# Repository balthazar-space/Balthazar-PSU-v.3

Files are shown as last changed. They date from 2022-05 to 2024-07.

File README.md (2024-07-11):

# Balthazar

Open-hardware laptop computer modules description and concept.

These are electronic schematic modules as presented at https://balthazar.space/wiki/Balthazar with the main aim for team access. See the [main repository](https://github.com/balthazar-space/balthazar) for other designs.

# Balthazar PSU v.3 

Module BalthazarPSU3 is a combined 1S battery charger, buck-boost converter to 5V, boost converter to 12V and stereo power amplifier. 

KiCad 6.99 files.

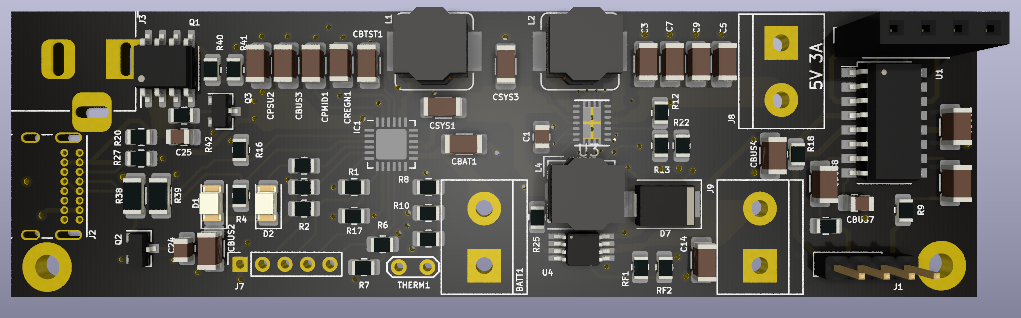
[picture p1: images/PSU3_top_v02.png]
Top


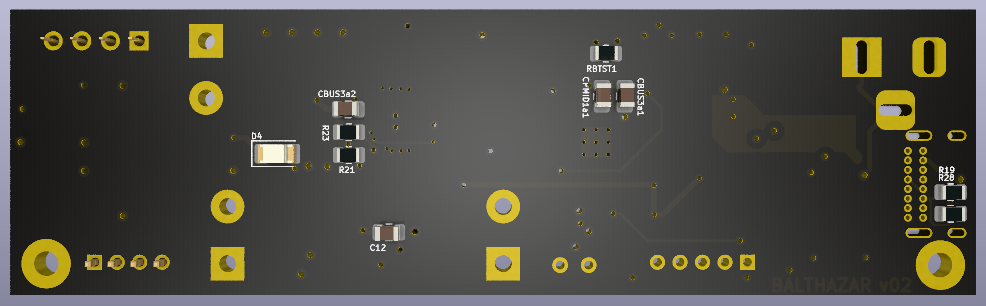
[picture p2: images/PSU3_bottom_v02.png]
Bottom


## License

All resources except the keyboard firmware - which is licensed with with GPLv3 or later - licensed under the CERN Open Hardware Licence CERN-OHL W V.2.0

Version 2.0 of the CERN-OHL introduces three variants of the licence – strongly (S) reciprocal, weakly (W) reciprocal and permissive (P) – which aim to address specific constraints caused by different collaboration models currently used in open-hardware projects. 

The first two variants mean that if any product is made using an open hardware design, the design of that product, including any improvements or modifications, should be made available under the same licence as that of the original product. Permissive licences do not impose this condition.

See the [LICENSE.md](./LICENSE.md) file for more information.

## Funding

This project is funded through the [NGI Zero Entrust Fund](https://nlnet.nl/entrust), a fund
established by [NLnet](https://nlnet.nl) with financial support from the European Commission's
[Next Generation Internet](https://ngi.eu) program. Learn more on the [NLnet project page](https://nlnet.nl/project/Balthazar-Casing/).

[NLNet foundation logo](https://nlnet.nl)
[NGI0 Entrust Logo](https://nlnet.nl/entrust)

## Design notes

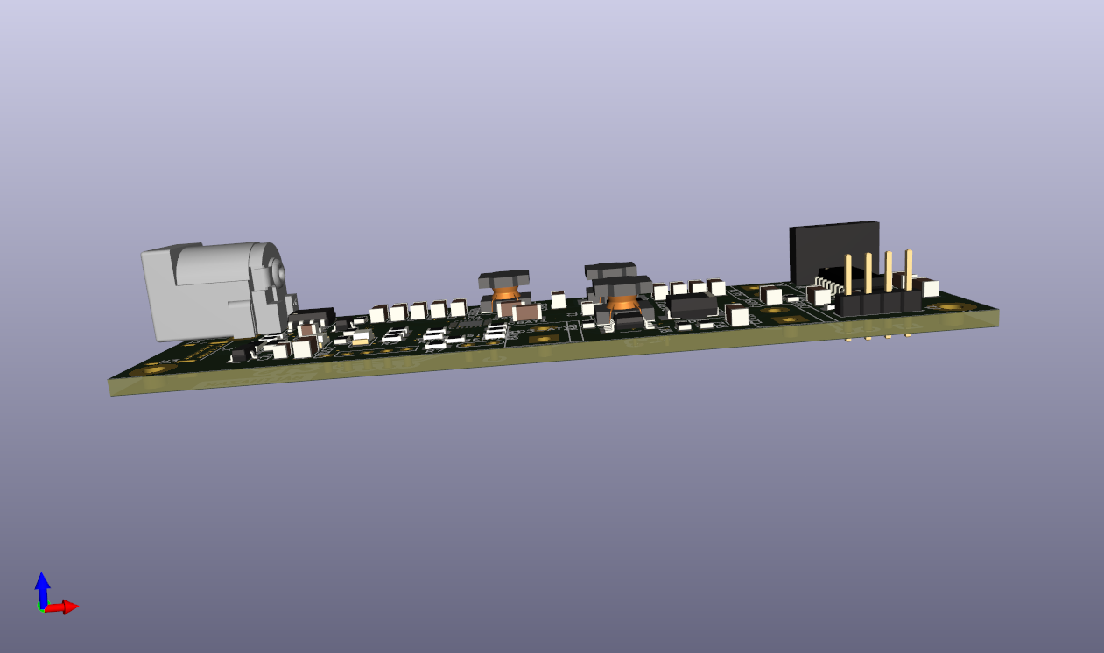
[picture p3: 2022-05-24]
images/BalthazarPSU3-3.png

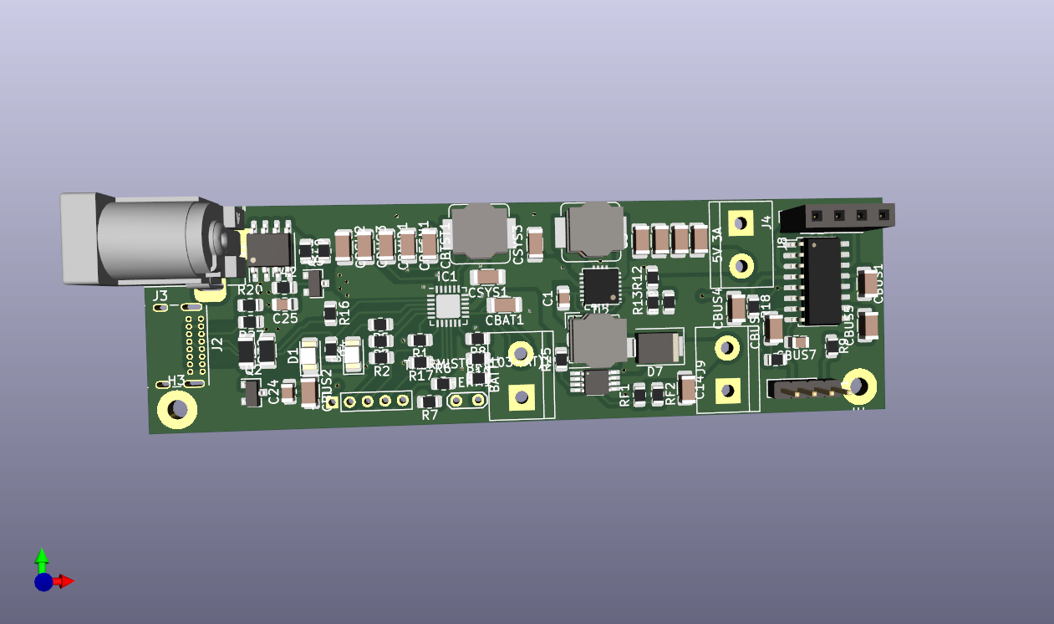
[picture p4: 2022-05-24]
images/BalthazarPSU3-1.png

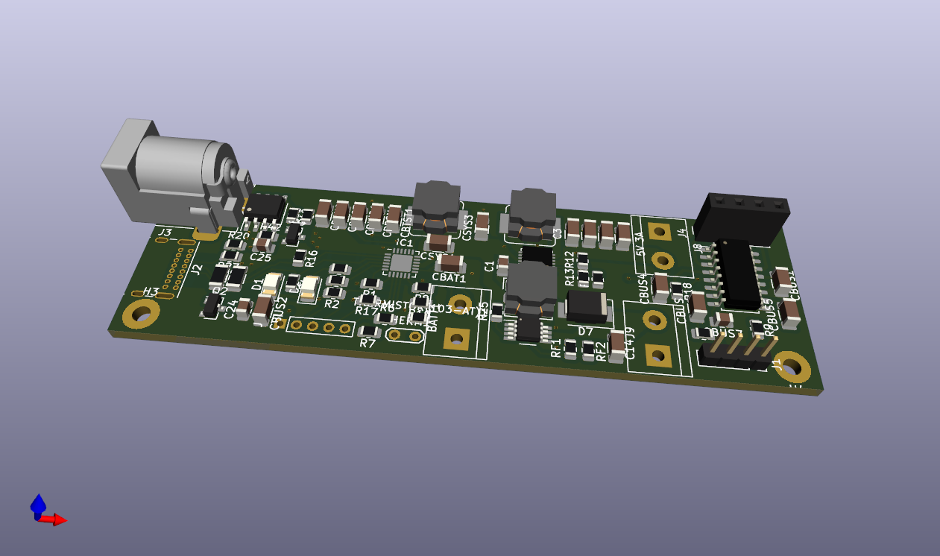
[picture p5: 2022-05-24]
images/BalthazarPSU3-2.png

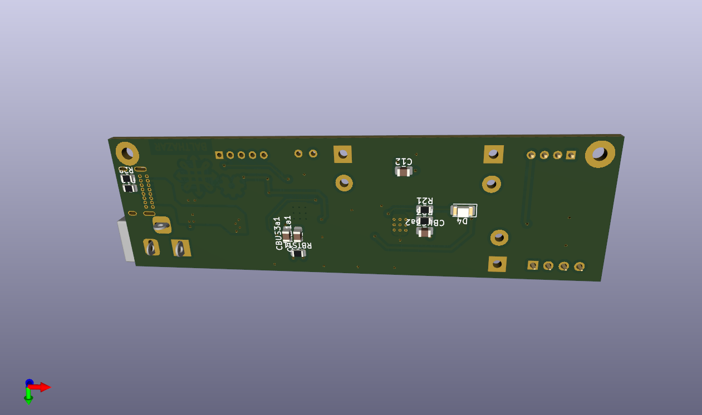
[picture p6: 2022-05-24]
images/BalthazarPSU3-4.png

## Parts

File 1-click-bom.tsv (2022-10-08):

References | Qty | Description | Manufacturer | MPN | Manufacturer | MPN | Manufacturer | MPN | Manufacturer | MPN | Digikey | Mouser | RS | Newark | Farnell | LCSC | JLC Assembly
C1, C24, CBUS3a1, CBUS3a2, CBUS7, CPMID1a1 | 6 | 0.1uF C_0805_2012Metric | KEMET | C0402C104K4RACTU | Yageo | CC0805KRX7R9BB104 | Murata | GRM21BR71H104KA01L |  |  | 311-1140-6-ND | 80C0402C104K4R | 8015145P |  | 1288252
C3, C5, C7, C9, C14 | 5 | 22uF C_1206_3216Metric | AVX | 12066C226KAT2A | Taiyo Yuden | EMK316ABJ226ML-T |  |  |  |  | 587-3328-6-ND | 963EMK316ABJ226MLT | 1356734 |  | 1657942
C12 | 1 | 4.7pF C_0805_2012Metric | KEMET | C0805C479C5GACTU | KEMET | C0805C479D5GACTU |  |  |  |  | 399-C0805C479D5GAC7800DKR-ND | 80C0805C479D5G | 1464340P |  | 1800809
C25 | 1 | 1nF C_0805_2012Metric | KEMET | C0805C102J1GACTU | KEMET | C0805C102K5RACTU |  |  |  |  | 399-C0805C102K5RAC7800DKR-ND | 80C0805C102K5R | 8029958P |  | 1414660
R1, R2, R3, R6, R16, R17, R18, R42 | 8 | 10K R_0805_2012Metric | Panasonic | ERJ-3EKF1002V | Panasonic | ERJ-6ENF1002V | TE Connectivity | CPF0805B10KE | Panasonic | ERJ-6GEYJ103V | P10.0KHCT-ND | 667ERJ6ENF1002V | 6662594 |  | 2303192
R4, R5, R8, R9, R11, R21 | 6 | 2K2 R_0805_2012Metric | Panasonic | ERJ-2RKF2201X | Panasonic | ERJ-3GEYJ222V | TE Connectivity | CRG0805F2K2 | Panasonic | ERJP06F2201V | P2.2KGCT-ND | 667ERJ2RKF2201X | 7217775P |  | 1750759
R12, R23 | 2 | 1M R_0805_2012Metric | Panasonic | ERJ-3GEYJ105V | Panasonic | ERJ-6GEYJ105V |  |  |  |  | P1.0MGCT-ND | 667ERJ3GEYJ105V | 7326536 |  | 2057738
R19, R27 | 2 | 5K1 R_0805_2012Metric | Panasonic | ERJ-6ENF5101V | Yageo | RC0805FR-075K1L |  |  |  |  | 311-5.10KCRDKR-ND | 667ERJ6ENF5101V | 1995733P |  | 3496074
R20, R28 | 2 | 56K 0805_2012Metric | Yageo | RMCF0805JT56K0 | Yageo | AC0805FR-0756KL | Yageo | RC0805FR-0756KL |  |  | 311-56.0KCRCT-ND | 603RC0805FR0756KL | 1995730 |  | 9237844
R7 | 1 | 270R 0805_2012Metric | TE Connectivity | 3520270RJT | TE Connectivity | CRG0805F270R | Panasonic | ERJ-6GEYJ271V |  |  | A126355CT-ND | 667ERJ6GEYJ271V | 2240339 |  | 3399601
R10 | 1 | 6K8 0805_2012Metric | Yageo | RC0805FR-076K8L | Yageo | AC0805FR-076K8L |  |  |  |  | 311-6.80KCRCT-ND | 603AC0805FR076K8L | 1995745 |  | 9237739RL
R13 | 1 | 180K R_0805_2012Metric | Yageo | RC0805JR-07180KL | Bourns | CR0805-JW-184ELF |  |  |  |  | 311-180KARCT-ND | 603RC0805JR07180KL |  |  | 9234284
R22 | 1 | 270K R_0805_2012Metric | Yageo | RC0805JR-07270KL |  | RC0805JR-07270KL |  |  |  |  | 311-270KARDKR-ND | 603RC0805JR07270KL |  |  | 9234306
R25 | 1 | 150K R_0805_2012Metric | Yageo | RC0805JR-07150KL |  | RC0805JR-07150KL |  |  |  |  | 311-150KARDKR-ND | 603RC0805JR07150KL |  |  | 9234276
R38 | 1 | 120K R_1206_3216Metric | Yageo | AC1206JR-07150KL |  | AC1206JR-07150KL |  |  |  |  | YAG3920CT-ND | 603AC1206JR07150KL
R39 | 1 | 49K9 R_1206_3216Metric | Yageo | RC1206FR-0749K9L |  | RC1206FR-0749K9L |  |  |  |  | 311-49.9KFRCT-ND | 603RC1206FR0749K9L |  |  | 3951060RL
R40 | 1 | 270K R_0805_2012Metric | Yageo | RC0805JR-07270KL |  | RC0805JR-07270KL |  |  |  |  | 311-270KARDKR-ND | 603RC0805JR07270KL |  |  | 9234306
R41 | 1 | 100K R_0805_2012Metric | Yageo | RC0805FR-13100KL |  | RC0805FR-13100KL |  |  |  |  | 13-RC0805FR-13100KLDKR-ND | 603RC0805FR13100KL |  |  | 3951189RL
L1 | 1 | 2.2uH SRP7028A | Bourns | SRP7028A-2R2M |  |  |  |  |  |  | SRP7028A-2R2MCT-ND | 652SRP7028A2R2M |  |  | 2434097
L2 | 1 | 1.5uH SRP7028A | Bourns | SRP7028A-1R5M |  |  |  |  |  |  | SRP7028A-1R5MCT-ND | 652SRP7028A1R5M | 2231849P |  | 2434095
L4 | 1 | 4.7uH SRP5030T | Bourns | SRP5030T-4R7M |  |  |  |  |  |  | SRP5030T-4R7MDKR-ND | 652SRP5030T4R7M | 7763985P |  | 2309887
D1, D2, D4 | 3 | Led LED_1206_3216Metric | Stanley Electric | RPG1102W-660-TR |  | RPG1102W-660-TR |  |  |  |  | 404-1232-1-ND | 327RPG1102W660TR
D7 | 1 | B320 | Bourns | CD214B-B320R | Diodes Inc. | B320B-13-F | Diodes Inc. | B330-13-F |  |  | B320B-FDICT-ND | 652CD214BB320R | 7513269 |  | 3944811RL
U1 | 1 | PAM8403 | Diodes Inc. | PAM8403DR-H | Diodes Inc. | PAM8403DR |  |  |  |  | PAM8403DR-HDICT-ND | 621PAM8403DRH | 7902975P |  | 3373823
U2 | 1 | TPS63020 | Texas Instruments | TPS63020DSJT |  |  |  |  |  |  | 296-27230-2-ND | 595TPS63020DSJT | 8123808 |  | 3007458
U4 | 1 | LM2623 | Texas Instruments | LM2623AMM/NOPB | Texas Instruments | LM2623MM/NOPB |  |  |  |  | LM2623AMM/NOPBCT-ND | 926LM2623AMM/NOPB | 5333901 |  | 3121524RL
CBTST1, CBUS2, CBUS3, CBUS5, CBUS8, CPSU2, CREGN1 | 7 | 1uF C_1206_3216Metric | KEMET | C1206C105K3RACTU |  |  |  |  |  |  | 399-C1206C105K3RAC7800DKR-ND | 80C1206C105K3R | 4348110P |  | 9227865
CBAT1, CBUS1, CBUS4, CPMID1, CSYS1, CSYS3 | 6 | 10uF C_1206_3216Metric | KEMET | T491A106M016AT |  |  |  |  |  |  | 399-3687-6-ND | 80T491A106M016 | 8015454P |  | 1650980
Q2, Q3 | 2 | BSS138 | Nexperia | BSS138P,215 | Nexperia | BSS138BK,215 | ROHM | BSS138BKT116 |  |  | 846-BSS138BKT116CT-ND | 771BSS138P215 | 7920891P |  | 2053833
BATT1 | 1 | 1s LiPo TerminalBlock_bornier-2_P5.08mm |  | OQ0254500000G |  |  |  |  |  |  |  | 649OQ02545000J0G
IC1 | 1 | BQ24193 | Texas Instruments | BQ24193RGER |  |  |  |  |  |  | 296-35046-2-ND | 595BQ24193RGER
Q1 | 1 | IRF7404 | Infineon | IRF7404TRPBF |  |  |  |  |  |  | IRF7404PBFCT-ND | 942IRF7404TRPBF | 1781525 |  | 2468018
RBTST1 | 1 | R R_0805_2012Metric
RF1 | 1 | 820K R_0805_2012Metric | TE Connectivity | CRGP0805F820K | Panasonic | ERA6AEB824V |  |  |  |  | A130512DKR-ND | 279CRGP0805F820K | 566418P |  | 2861130
RF2 | 1 | 100K R_0805_2012Metric | Panasonic | ERJ-6ENF1003V | TE Connectivity | CPF0805B100KE |  |  |  |  | P100KCDKR-ND | 667ERJ6ENF1003V | 6662673P |  | 2303757
THERM1 | 1 | thermistor TestPoint_2Pads_Pitch2.54mm_Drill0.8mm
THERMISTOR(103-AT)1 | 1 | 10K R_0805_2012Metric | Panasonic | ERJ-6ENF1002V | TE Connectivity | CPF0805B10KE |  |  |  |  | A106043CT-ND | 667ERJ6ENF1002V | 6662594 |  | 2303654
J1 | 1 | AudioIN PinSocket_1x04_P2.00mm_Vertical |  | SQT-102-03-F-S |  |  |  |  |  |  |  | 200SQT10203FS
J2 | 1 | USB_C_Receptacle_USB2.0 USB_C_Receptacle_GCT_USB4085 |  | USB4085-GF-A |  |  |  |  |  |  |  | 640USB4085GFA
J3 | 1 | 5-15V / 3-5A BarrelJack_Horizontal |  | PRT-00119 |  |  |  |  |  |  |  | 474PRT00119
J4 | 1 | AudioOUT PinSocket_1x04_P2.54mm_Vertical |  | 929850-01-04-RA |  |  |  |  |  |  |  | 5179298500104RA
J7 | 1 | uC host PinSocket_1x05_P2.00mm_Vertical |  | SQT-105-01-F-S |  |  |  |  |  |  |  | 200SQT10501FS
J8 | 1 | 5V 3A TerminalBlock_bornier-2_P5.08mm |  | OQ0254500000G |  |  |  |  |  |  |  | 649OQ02545000J0G
J9 | 1 | 12V 2A TerminalBlock_bornier-2_P5.08mm |  | OQ0254500000G |  |  |  |  |  |  |  | 649OQ02545000J0G

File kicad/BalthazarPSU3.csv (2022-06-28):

Id | Designator | Footprint | Quantity | Designation | Supplier and ref
1 | CBAT1,CBUS1,CBUS4,CPMID1,CSYS1,CSYS3 | C_1206_3216Metric | 6 | 10uF
2 | CBTST1,CBUS2,CBUS3,CBUS5,CBUS8,CPSU2,CREGN1 | C_1206_3216Metric | 7 | 1uF
3 | CBUS7,C1,C24,CBUS3a1,CBUS3a2,CPMID1a1 | C_0805_2012Metric | 6 | 0.1uF
4 | D1,D2,D4 | LED_1206_3216Metric | 3 | Led
5 | R4,R5,R8,R9,R11,R21 | R_0805_2012Metric | 6 | 2K2
6 | R7 | R_0805_2012Metric | 1 | 265
7 | R10 | R_0805_2012Metric | 1 | 6K8
8 | C3,C5,C7,C9,C14 | C_1206_3216Metric | 5 | 22uF
9 | R12,R23 | R_0805_2012Metric | 2 | 1M
10 | R13 | R_0805_2012Metric | 1 | 180K
11 | THERMISTOR(103-AT)1,R18,R42,R1,R2,R3,R6,R16,R17 | R_0805_2012Metric | 9 | 10K
12 | U1 | SOP-16_4.55x10.3mm_P1.27mm | 1 | PAM8403-SOP16
13 | IC1 | QFN-24-1EP_4x4mm_P0.5mm_EP2.7x2.7mm_ThermalVias | 1 | BQ24193
14 | THERM1 | TestPoint_2Pads_Pitch2.54mm_Drill0.8mm | 1 | thermistor
15 | R25 | R_0805_2012Metric | 1 | 150K
16 | U2 | WSON-14-1EP_4.0x4.0mm_P0.5mm_EP2.6x2.6mmThermalPads | 1 | TPS63020
17 | BATT1 | TerminalBlock_bornier-2_P5.08mm | 1 | 1s LiPo
18 | J8 | TerminalBlock_bornier-2_P5.08mm | 1 | 5V 2A
19 | J9 | TerminalBlock_bornier-2_P5.08mm | 1 | 12V 2A
20 | J2 | USB_C_Receptacle_GCT_USB4085 | 1 | USB_C_Receptacle_USB2.0
21 | L1 | L_Bourns_SRP7028A_7.3x6.6mm | 1 | 2.2uH 4A
22 | L2 | L_Bourns_SRP7028A_7.3x6.6mm | 1 | 1.5uH 4A
23 | J3 | TerminalBlock_bornier-2_P5.08mm | 1 | 5-15V/3A
24 | C25 | C_0805_2012Metric | 1 | 1nF
25 | Q2,Q3 | SOT-23 | 2 | BSS138
26 | R20,R28 | R_0805_2012Metric | 2 | 56K
27 | R27,R19 | R_0805_2012Metric | 2 | 5K1
28 | R40 | R_0805_2012Metric | 1 | 262K
29 | R41,RF2 | R_0805_2012Metric | 2 | 100K
30 | J4 | PinSocket_1x04_P2.54mm_Vertical | 1 | AudioOUT
31 | J7 | PinSocket_1x05_P2.00mm_Vertical | 1 | uC host
32 | J1 | PinSocket_1x04_P2.00mm_Vertical | 1 | AudioIN
33 | R38 | R_1206_3216Metric | 1 | 120K
34 | R39 | R_1206_3216Metric | 1 | 49K9
35 | H1,H3,H4 | MountingHole_2.2mm_M2_Pad | 3 | MountingHole_Pad
36 | Q1 | SOIC-8_3.9x4.9mm_P1.27mm | 1 | IRF7404
37 | RF1 | R_0805_2012Metric | 1 | 820K
38 | L4 | L_Bourns_SRP5030T | 1 | 4.7uH 2A
39 | D7 | D_SMB | 1 | B320
40 | R22 | R_0805_2012Metric | 1 | 270K
41 | U4 | VSSOP-8_3.0x3.0mm_P0.65mm | 1 | LM2623
42 | RBTST1 | R_0805_2012Metric | 1 | R
43 | G*** | BALTHAZARlogo150 | 1 | LOGO
44 | C12 | C_0805_2012Metric | 1 | 4.7pF

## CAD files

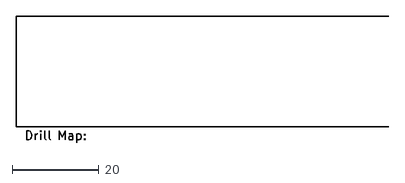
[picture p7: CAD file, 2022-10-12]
kicad/gerbers/BalthazarPSU3-NPTH-drl_map.dxf
85.9 x 29.1

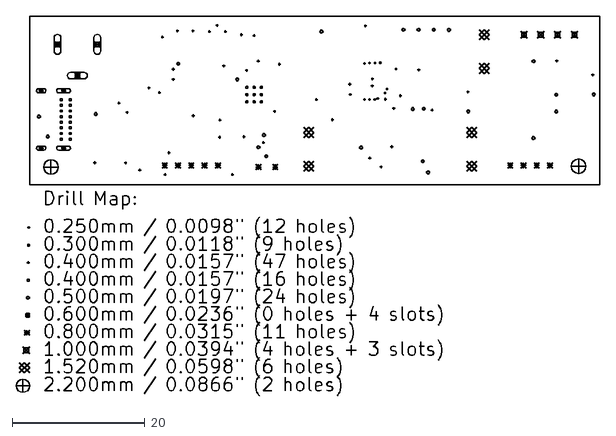
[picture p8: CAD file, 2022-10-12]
kicad/gerbers/BalthazarPSU3-PTH-drl_map.dxf
87.9 x 57.2

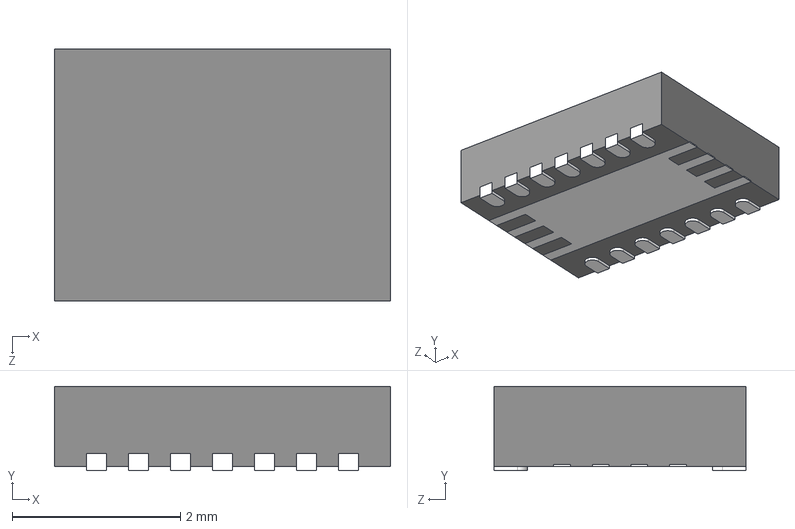
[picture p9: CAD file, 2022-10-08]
kicad/footprint/TPS63020/TPS63020.step
4.00 x 1.00 x 3.00 mm

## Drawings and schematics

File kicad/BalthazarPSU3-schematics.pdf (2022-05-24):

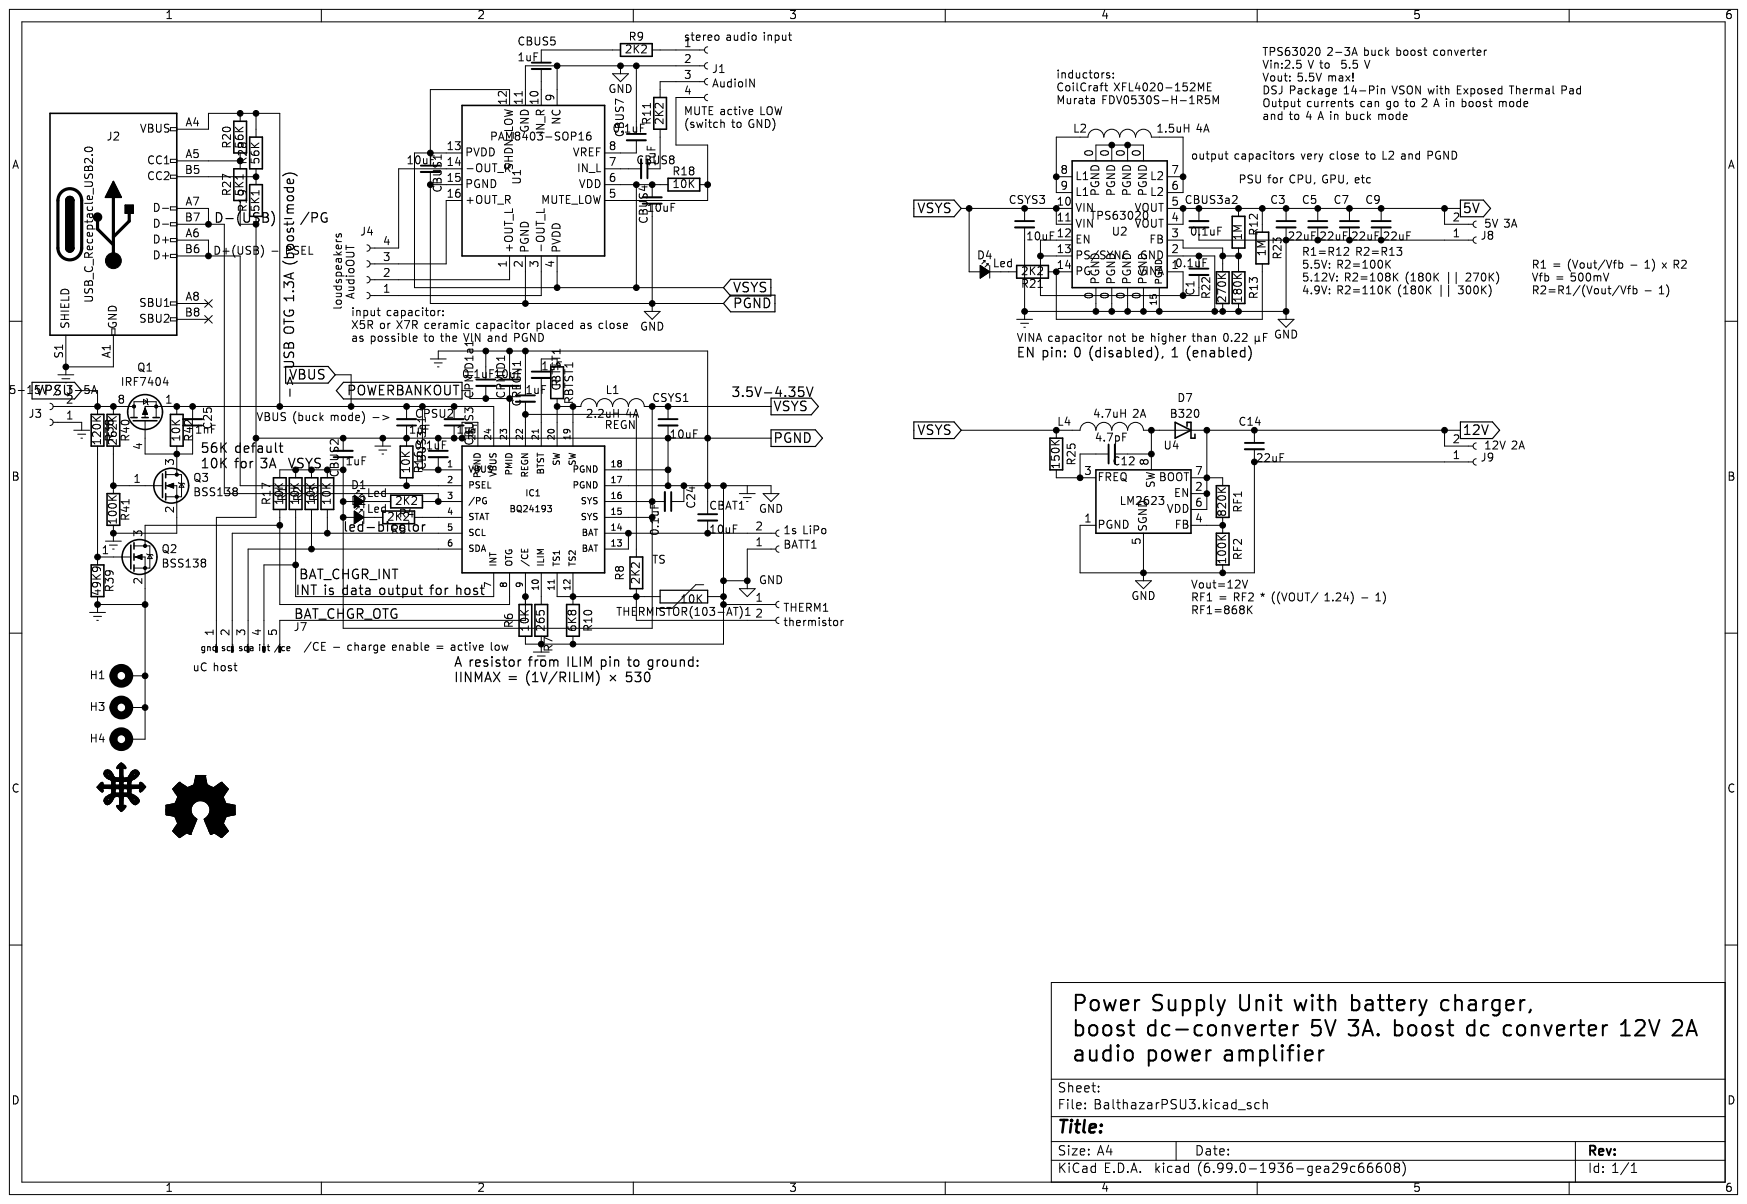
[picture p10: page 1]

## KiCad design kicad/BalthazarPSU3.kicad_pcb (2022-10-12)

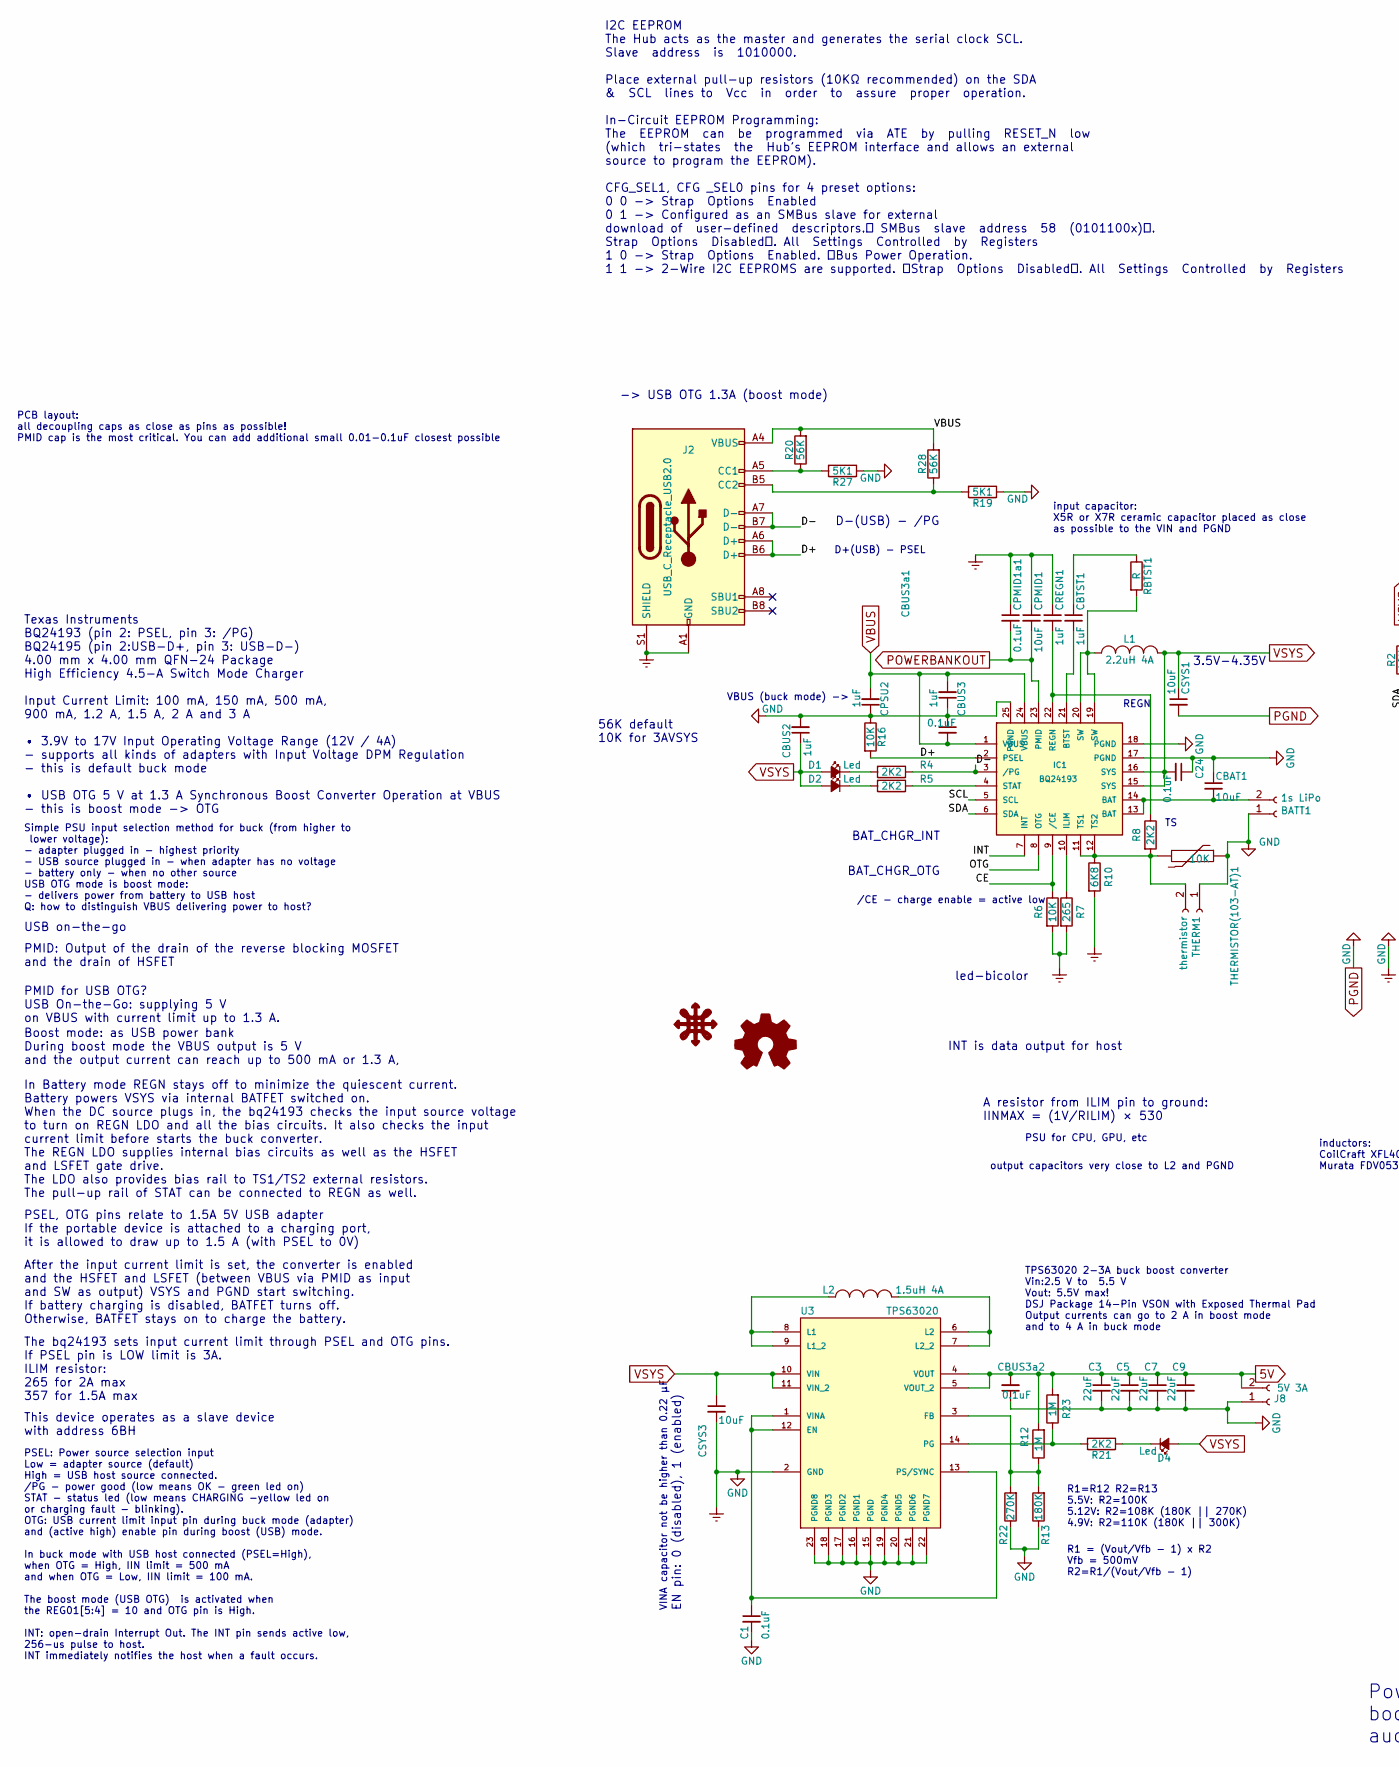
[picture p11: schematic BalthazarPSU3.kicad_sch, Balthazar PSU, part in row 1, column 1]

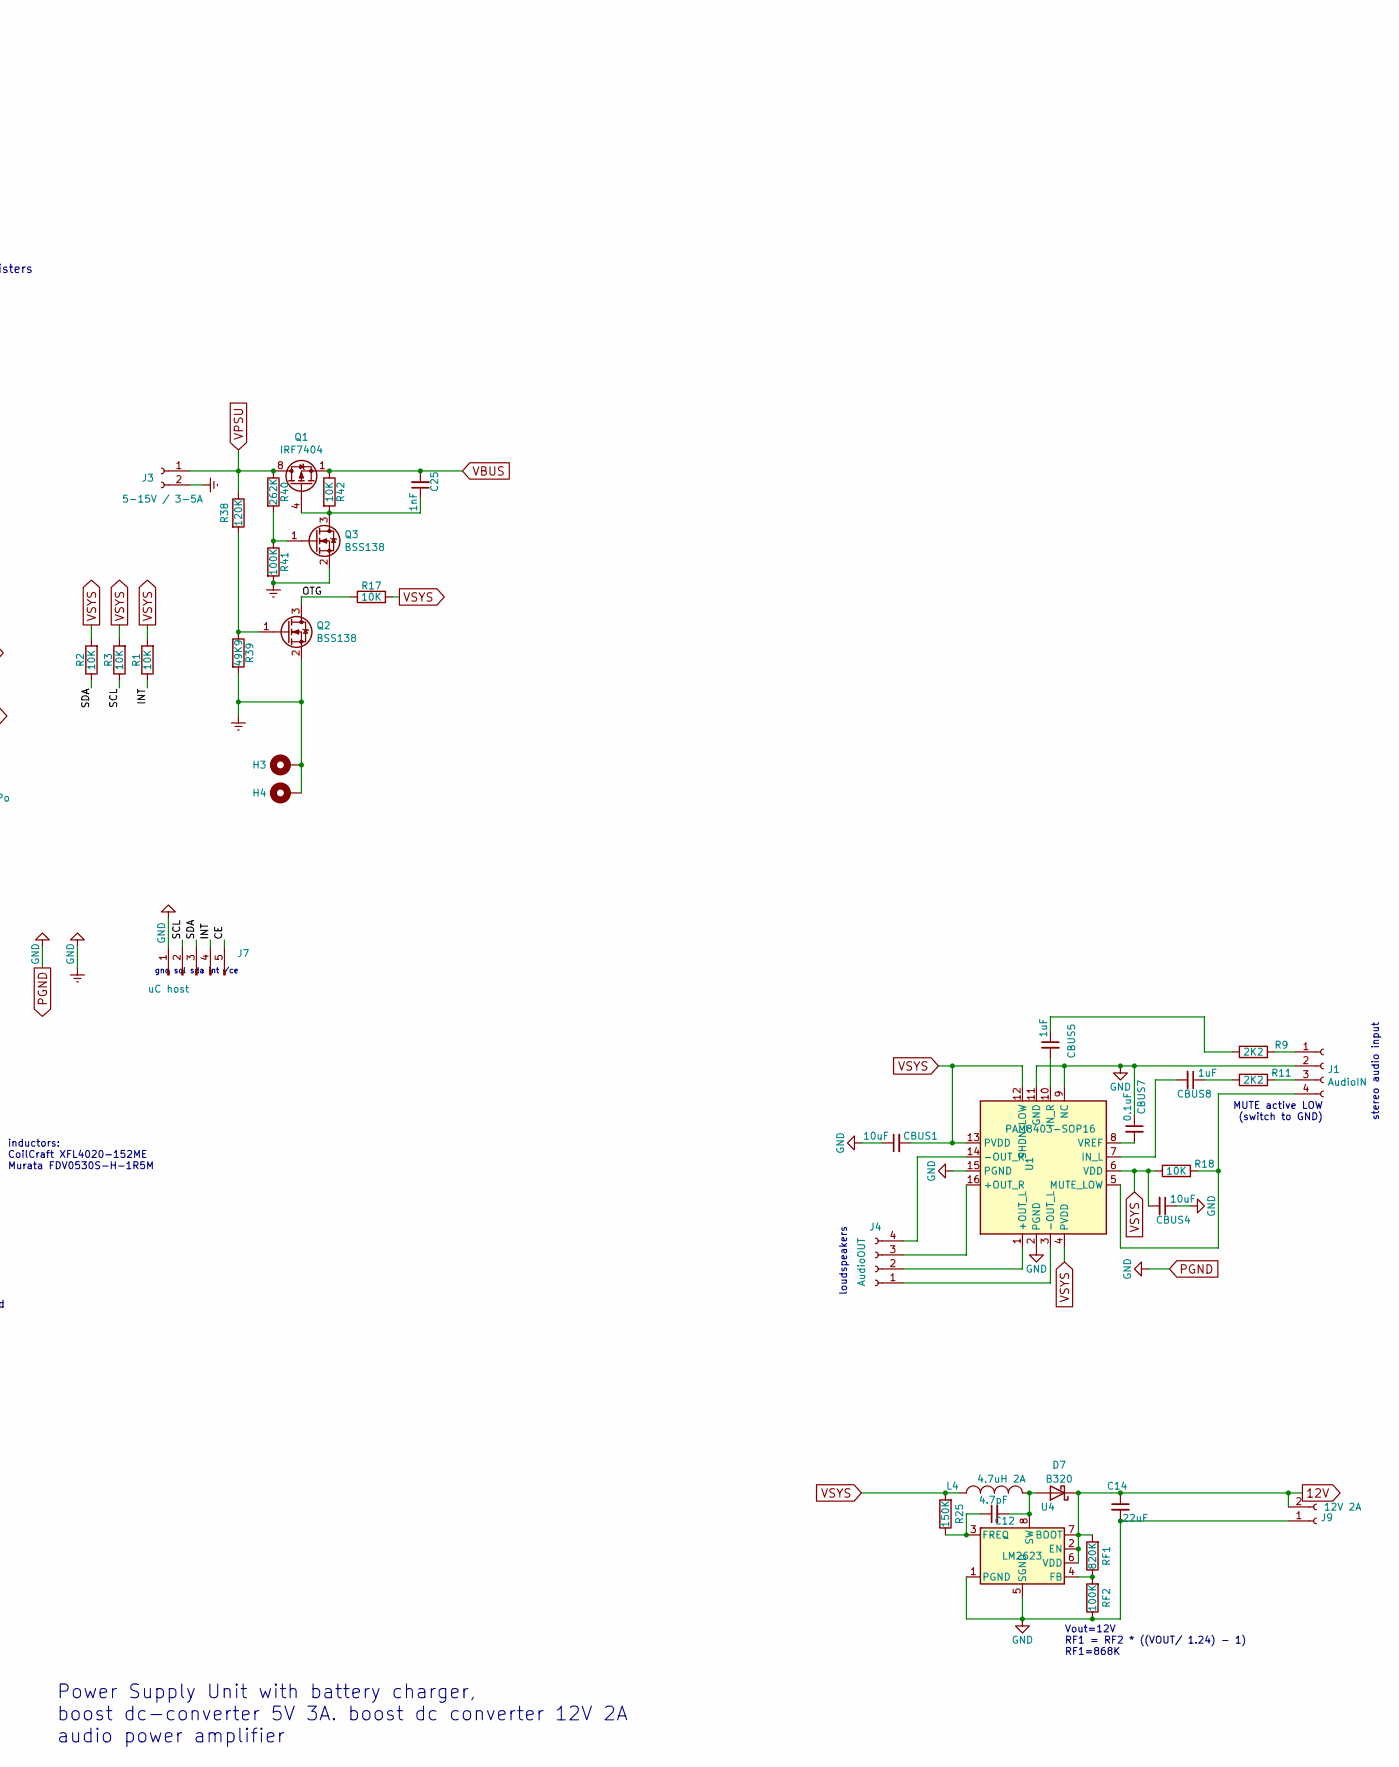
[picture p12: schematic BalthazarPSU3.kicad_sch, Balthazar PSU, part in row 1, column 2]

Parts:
BATT1: 1s LiPo; TerminalBlock_bornier-2_P5.08mm
C1, C24: 0.1uF; C_0805_2012Metric
C3, C5, C7, C9, C14: 22uF; C_1206_3216Metric
C12: 4.7pF; C_0805_2012Metric
C25: 1nF; C_0805_2012Metric
CBAT1: 10uF; C_1206_3216Metric
CBTST1: 1uF; C_1206_3216Metric
CBUS1, CBUS4: 10uF; C_1206_3216Metric
CBUS2, CBUS3, CBUS5, CBUS8: 1uF; C_1206_3216Metric
CBUS3a1, CBUS3a2, CBUS7: 0.1uF; C_0805_2012Metric
CPMID1: 10uF; C_1206_3216Metric
CPMID1a1: 0.1uF; C_0805_2012Metric
CPSU2: 1uF; C_1206_3216Metric
CREGN1: 1uF; C_1206_3216Metric
CSYS1, CSYS3: 10uF; C_1206_3216Metric
D1, D2, D4: Led; LED_1206_3216Metric
D7: B320; D_SMB
H3: hole; MountingHole_2.2mm_M2_Pad
H4: MountingHole_Pad; MountingHole_2.2mm_M2_Pad
IC1: BQ24193; QFN-24-1EP_4x4mm_P0.5mm_EP2.7x2.7mm_ThermalVias
J1: AudioIN; PinSocket_1x04_P2.00mm_Vertical
J2: USB_C_Receptacle_USB2.0; USB_C_Receptacle_GCT_USB4085
J3: 5-15V / 3-5A; BarrelJack_Horizontal
J4: AudioOUT; PinSocket_1x04_P2.54mm_Vertical
J7: uC host; PinSocket_1x05_P2.00mm_Vertical
J8: 5V 3A; TerminalBlock_bornier-2_P5.08mm
J9: 12V 2A; TerminalBlock_bornier-2_P5.08mm
L1: 2.2uH 4A; L_Bourns_SRP7028A_7.3x6.6mm
L2: 1.5uH 4A; L_Bourns_SRP7028A_7.3x6.6mm
L4: 4.7uH 2A; L_Bourns_SRP5030T
Q1: IRF7404; SOIC-8_3.9x4.9mm_P1.27mm
Q2, Q3: BSS138; SOT-23
R1, R2, R3, R6, R16, R17, R18, R42: 10K; R_0805_2012Metric
R4, R5, R8, R9, R11, R21: 2K2; R_0805_2012Metric
R7: 265; R_0805_2012Metric
R10: 6K8; R_0805_2012Metric
R12, R23: 1M; R_0805_2012Metric
R13: 180K; R_0805_2012Metric
R19, R27: 5K1; R_0805_2012Metric
R20, R28: 56K; R_0805_2012Metric
R22: 270K; R_0805_2012Metric
R25: 150K; R_0805_2012Metric
R38: 120K; R_1206_3216Metric
R39: 49K9; R_1206_3216Metric
R40: 262K; R_0805_2012Metric
R41: 100K; R_0805_2012Metric
RBTST1: R; R_0805_2012Metric
RF1: 820K; R_0805_2012Metric
RF2: 100K; R_0805_2012Metric
THERM1: thermistor; TestPoint_2Pads_Pitch2.54mm_Drill0.8mm
THERMISTOR(103-AT)1: 10K; R_0805_2012Metric
U1: PAM8403-SOP16; SOP-16_4.4x10.4mm_P1.27mm
U3: TPS63020; QFN14-3X4MM
U4: LM2623; VSSOP-8_3.0x3.0mm_P0.65mm

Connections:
5V: C3.1, C5.1, C7.1, C9.1, CBUS3a2.2, J8.2, R12.2, R23.2, U3.4 (VOUT), U3.5 (VOUT_2)
12V: C14.1, D7.1 (K), J9.2, RF1.2, U4.2 (EN), U4.6 (VDD), U4.7 (BOOT)
/CE: IC1.9 (/CE), J7.5, R6.1
/D+: IC1.2 (PSEL), J2.A6 (D+), J2.B6 (D+), R16.2
/D-: IC1.3 (/PG), J2.A7 (D-), J2.B7 (D-), R4.1
/INT: IC1.7 (INT), J7.4, R1.1
/OTG: IC1.8 (OTG), Q2.3 (D), R17.1
/SCL: IC1.5 (SCL), J7.2, R3.1
/SDA: IC1.6 (SDA), J7.3, R2.1
unnamed: BATT1.2, CBAT1.2, IC1.13 (BAT), IC1.14 (BAT)
unnamed: CBTST1.1, RBTST1.1
unnamed: CBUS5.1, R9.1
unnamed: CBUS8.1, R11.1
unnamed: D1.2 (C), R4.2
unnamed: D2.2 (C), R5.2
unnamed: D4.2 (C), R21.1
unnamed: C12.2, D7.2 (A), L4.2, U4.8 (SW)
unnamed: CBTST1.2, IC1.21 (BTST)
unnamed: IC1.10 (ILIM), R7.1
unnamed: CREGN1.2, IC1.22 (REGN), R8.1
unnamed: IC1.4 (STAT), R5.1
unnamed: IC1.19 (SW), IC1.20 (SW), L1.1, RBTST1.2
unnamed: IC1.11 (TS1), IC1.12 (TS2), R8.2, R10.1, THERM1.2, THERMISTOR(103-AT)1.2
unnamed: J1.1, R9.2
unnamed: J1.3, R11.2
unnamed: J1.4, R18.2, U1.5 (MUTE_LOW)
unnamed: J2.A5 (CC1), R20.1, R27.2
unnamed: J2.B5 (CC2), R19.2, R28.1
unnamed: J4.1, U1.3 (-OUT_L)
unnamed: J4.2, U1.1 (+OUT_L)
unnamed: J4.3, U1.16 (+OUT_R)
unnamed: J4.4, U1.14 (-OUT_R)
unnamed: C25.1, Q1.4 (G), Q3.3 (D), R42.2
unnamed: Q2.1 (G), R38.2, R39.1
unnamed: Q3.1 (G), R40.2, R41.1
unnamed: CBUS8.2, U1.7 (IN_L)
unnamed: CBUS5.2, U1.10 (IN_R)
unnamed: CBUS7.2, U1.8 (VREF)
unnamed: C1.1, U3.1 (VINA), U3.12 (EN), U3.13 (PS/SYNC)
unnamed: R12.1, R13.2, R22.2, U3.3 (FB)
unnamed: L2.1, U3.8 (L1), U3.9 (L1_2)
unnamed: L2.2, U3.6 (L2), U3.7 (L2_2)
unnamed: R21.2, R23.1, U3.14 (PG)
unnamed: RF1.1, RF2.2, U4.4 (FB)
unnamed: C12.1, R25.1, U4.3 (FREQ)
PGND: BATT1.1, C1.2, C3.2, C5.2, C7.2, C9.2, C14.2, C24.1, CBAT1.1, CBUS1.1, CBUS2.2, CBUS3.1, CBUS3a1.1, CBUS3a2.1, CBUS4.1, CBUS7.1, CPMID1.1, CPMID1a1.1, CPSU2.1, CREGN1.1, CSYS1.2, CSYS3.2, H3.1, H4.1, IC1.17 (PGND), IC1.18 (PGND), IC1.25 (PGND), J1.2, J2.A1 (GND), J2.A12 (GND), J2.B1 (GND), J2.B12 (GND), J2.S1 (SHIELD), J3.2, J7.1, J8.1, J9.1, Q2.2 (S), Q3.2 (S), R6.2, R7.2, R10.2, R13.1, R16.1, R19.1, R22.1, R27.1, R39.2, R41.2, RF2.1, THERM1.1, THERMISTOR(103-AT)1.1, U1.2 (PGND), U1.9 (NC), U1.11 (GND), U1.15 (PGND), U3.2 (GND), U3.15 (PGND), U3.16 (PGND1), U3.17 (PGND2), U3.18 (PGND3), U3.19 (PGND4), U3.20 (PGND5), U3.21 (PGND6), U3.22 (PGND7), U3.23 (PGND8), U4.1 (PGND), U4.5 (SGND)
POWERBANKOUT: CPMID1.2, CPMID1a1.2, IC1.23 (PMID)
VBUS: C25.2, CBUS3.2, CBUS3a1.2, CPSU2.2, IC1.1 (VBUS), IC1.24 (VBUS), J2.A4 (VBUS), J2.A9 (VBUS), J2.B4 (VBUS), J2.B9 (VBUS), Q1.1 (S), Q1.2 (S), Q1.3 (S), R20.2, R28.2, R42.1
VPSU: J3.1, Q1.5 (D), Q1.6 (D), Q1.7 (D), Q1.8 (D), R38.1, R40.1
VSYS: C24.2, CBUS1.2, CBUS2.1, CBUS4.2, CSYS1.1, CSYS3.1, D1.1 (A), D2.1 (A), D4.1 (A), IC1.15 (SYS), IC1.16 (SYS), L1.2, L4.1, R1.2, R2.2, R3.2, R17.2, R18.1, R25.2, U1.4 (PVDD), U1.6 (VDD), U1.12 (SHDN_LOW), U1.13 (PVDD), U3.10 (VIN), U3.11 (VIN_2)

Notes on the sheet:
PSEL: Power source selection input Low = adapter source (default) High = USB host source connected. /PG - power good (low means OK - green led on) STAT - status led (low means CHARGING -yellow led on or charging fault - blinking). OTG: USB current limit input pin during buck mode (adapter) and (act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
output capacitors very close to L2 and PGND
REGN
PCB layout: all decoupling caps as close as pins as possible! PMID cap is the most critical. You can add additional small 0.01-0.1uF closest possible
3.5V-4.35V
56K default 10K for 3A
Texas Instruments BQ24193 (pin 2: PSEL, pin 3: /PG) BQ24195 (pin 2:USB-D+, pin 3: USB-D-) 4.00 mm x 4.00 mm QFN-24 Package High Efficiency 4.5-A Switch Mode Charger Input Current Limit: 100 mA, 150 mA, 500 mA, 900 mA, 1.2 A, 1.5 A, 2 A and 3 A • 3.9V to 17V Input Operating Voltage Range (12V / 4A) 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
PMID for USB OTG? USB On-the-Go: supplying 5 V on VBUS with current limit up to 1.3 A.
gnd scl sda int /ce
VBUS (buck mode) ->
D+(USB) - PSEL
stereo audio input
This device operates as a slave device with address 6BH
PMID: Output of the drain of the reverse blocking MOSFET and the drain of HSFET
In Battery mode REGN stays off to minimize the quiescent current. Battery powers VSYS via internal BATFET switched on. When the DC source plugs in, the bq24193 checks the input source voltage to turn on REGN LDO and all the bias circuits. It also checks the input current limit before starts the buc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
Vout=12V RF1 = RF2 * ((VOUT/ 1.24) − 1) RF1=868K
R1 = (Vout/Vfb - 1) x R2 Vfb = 500mV R2=R1/(Vout/Vfb - 1)
Boost mode: as USB power bank During boost mode the VBUS output is 5 V and the output current can reach up to 500 mA or 1.3 A,
-> USB OTG 1.3A (boost mode)
INT is data output for host
BAT_CHGR_OTG
The bq24193 sets input current limit through PSEL and OTG pins. If PSEL pin is LOW limit is 3A. ILIM resistor: 265 for 2A max 357 for 1.5A max
/CE - charge enable = active low
USB on-the-go
I2C EEPROM The Hub acts as the master and generates the serial clock SCL. Slave address is 1010000. Place external pull-up resistors (10KΩ recommended) on the SDA & SCL lines to Vcc in order to assure proper operation. In-Circuit EEPROM Programming: The EEPROM can be programmed via ATE by pulling R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
input capacitor: X5R or X7R ceramic capacitor placed as close as possible to the VIN and PGND
PSEL, OTG pins relate to 1.5A 5V USB adapter If the portable device is attached to a charging port, it is allowed to draw up to 1.5 A (with PSEL to 0V)
D-(USB) - /PG
Power Supply Unit with battery charger, boost dc-converter 5V 3A. boost dc converter 12V 2A audio power amplifier
VINA capacitor not be higher than 0.22 μF
TPS63020 2-3A buck boost converter Vin:2.5 V to 5.5 V Vout: 5.5V max! DSJ Package 14-Pin VSON with Exposed Thermal Pad Output currents can go to 2 A in boost mode and to 4 A in buck mode
MUTE active LOW (switch to GND)
R1=R12 R2=R13 5.5V: R2=100K 5.12V: R2=108K (180K || 270K) 4.9V: R2=110K (180K || 300K)
After the input current limit is set, the converter is enabled and the HSFET and LSFET (between VBUS via PMID as input and SW as output) VSYS and PGND start switching. If battery charging is disabled, BATFET turns off. Otherwise, BATFET stays on to charge the battery.
led-bicolor
A resistor from ILIM pin to ground: IINMAX = (1V/RILIM) × 530
PSU for CPU, GPU, etc
EN pin: 0 (disabled), 1 (enabled)
loudspeakers
VSYS

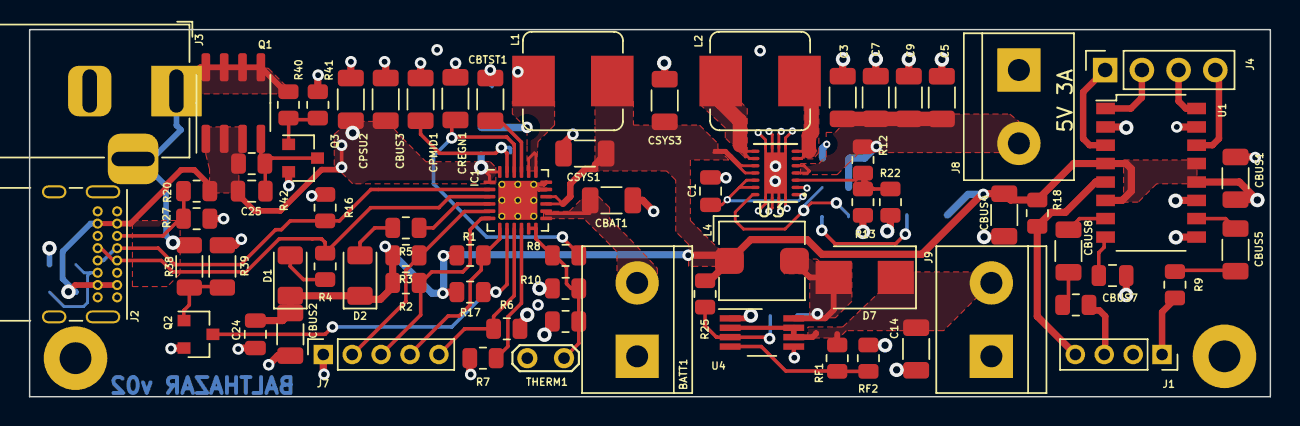
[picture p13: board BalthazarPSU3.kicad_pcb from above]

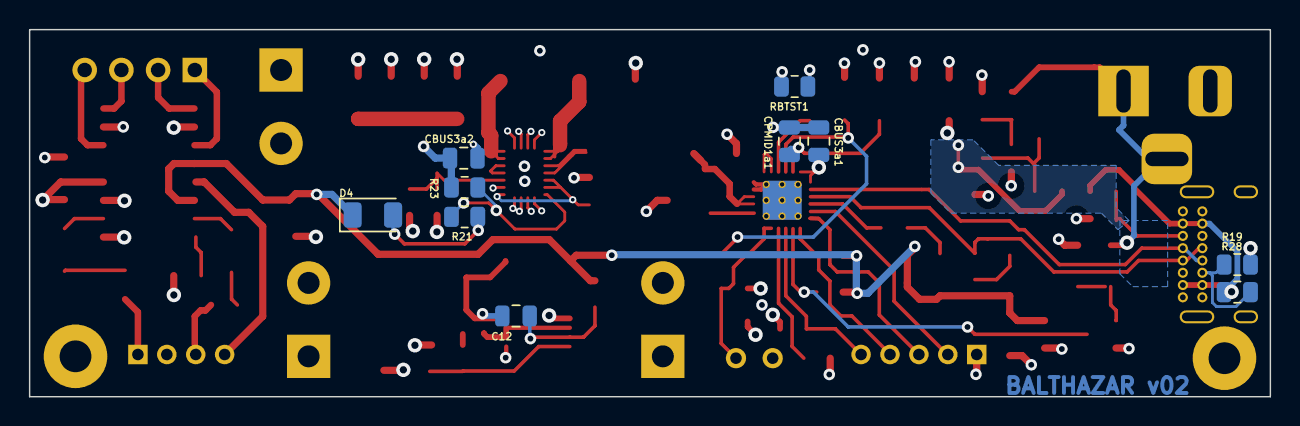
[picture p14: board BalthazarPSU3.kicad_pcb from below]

Board: 4 copper layers, 85.9 x 25.4 mm, 84 parts (10 on the bottom side), 50 nets.

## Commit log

2022-06-08 Adding interactive BOM
2022-06-28 Sorting files
    [1-click-bom.tsv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]
2022-06-29 Update 1-click_BOM
    [1-click-bom.tsv]
2022-07-10 Updating parts
    [1-click-bom.tsv]
2022-10-08 Adding new symbol and footprint for U2
    [BalthazarPSU3.kicad_pcb, BalthazarPSU3.kicad_sch, TPS63020.step]
2022-10-11 Switching to 4 layer board fix #10
    [BalthazarPSU3.kicad_pcb, BalthazarPSU3.kicad_sch]
2022-10-11 Adding info fix #9
    [BalthazarPSU3.kicad_pcb, BalthazarPSU3.kicad_sch]
2022-10-11 Removing all routed signal loops
    [BalthazarPSU3.kicad_pcb]
2022-10-11 Routing all signals fix #11 fix #7
    [BalthazarPSU3.kicad_pcb]
2022-10-11 For cleanup we need more space - switching schematics page to A3 #5
    [BalthazarPSU3.kicad_sch]
2022-10-11 MAking silkscreen text smaller #13
    [BalthazarPSU3.kicad_pcb]
2022-10-11 Moving Silkscreen text fix #13
    [BalthazarPSU3.kicad_pcb]
2022-10-11 fixing/checking design errors fix #12
    [BalthazarPSU3.kicad_pcb]
2022-10-11 Improving schematics #5
    [BalthazarPSU3.kicad_pcb, BalthazarPSU3.kicad_sch]
2022-10-11 Moving USB lines
    [BalthazarPSU3.kicad_sch]
2022-10-11 Moving more lines
    [BalthazarPSU3.kicad_sch]
2022-10-12 More line moves
    [BalthazarPSU3.kicad_sch]
2022-10-12 More line moves fix #5
    [BalthazarPSU3.kicad_sch]
2022-10-12 Adding production files fix #8
    [BalthazarPSU3-B_Cu.gbl, BalthazarPSU3-B_Mask.gbs, BalthazarPSU3-B_Paste.gbp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]

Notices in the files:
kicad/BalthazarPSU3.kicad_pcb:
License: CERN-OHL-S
